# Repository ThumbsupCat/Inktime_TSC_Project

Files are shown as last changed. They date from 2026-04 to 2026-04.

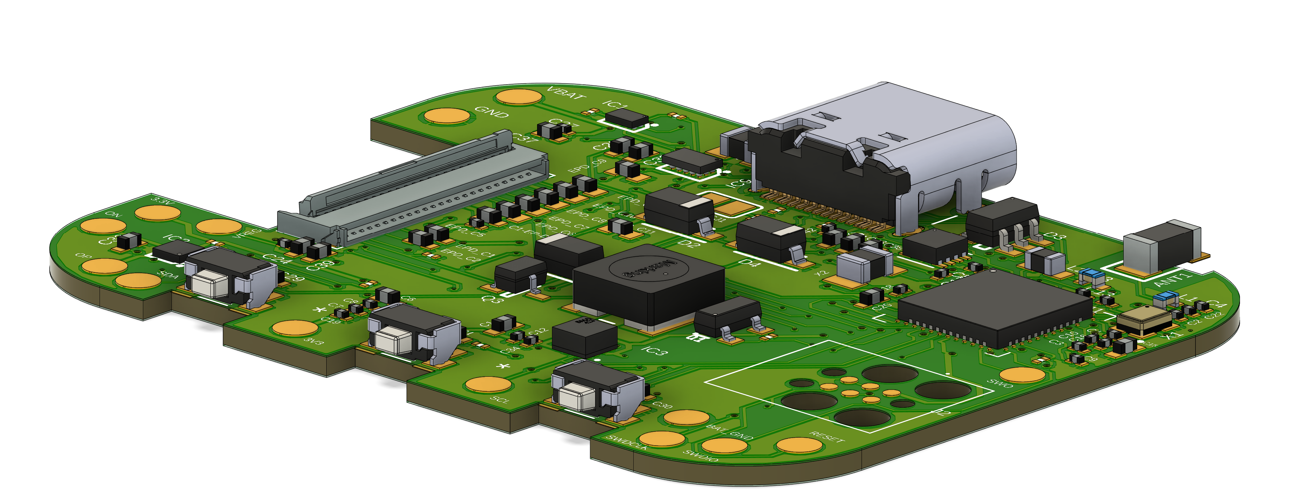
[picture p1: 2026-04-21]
Images/PCB_side_view.png

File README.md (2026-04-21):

# Inktime_TSC_Project

## Cuprins:

1. Hardware: - Schematicul si pcb-ul
2. Manufacturing: - Bill of Materials si Pick & Place
3. Mechanical: fisierele 3D
4. Images: Imaginile cu produsul final

## Descriere
InkTime este un ceas smart optimizat pentru autonomie maximă și lizibilitate 
în lumina soarelui. MVP-ul include:

- Display e-paper 1.54" (200×200) cu refresh parțial o dată pe minut
- Notificări BLE de pe telefon cu alertă haptic
- Numărare pași în timp real prin accelerometru cu pedometru integrat
- Încărcare USB-C și programare prin Tag-Connect TC2030 SWD

## Arhitectură
Sistemul este construit în jurul MCU-ului **nRF52840** care integrează 
procesor ARM Cortex-M4 și radio BLE 5.0.
Alimentarea este asigurată de un charger LiPo **BQ25180** conectat la 
USB-C și un regulator buck-boost **RT6160** care menține 3.3V stabil 
pe toată gama de descărcare a bateriei.

## Schema Bloc
Block Diagram

## Bill of Materials
| Ref | Component | Package | Funcție | LCSC | Datasheet |
|-----|---|---|---|---|---|
| U1 | nRF52840-QIAA | aQFN73 7×7mm | MCU + BLE 5.0 | [C190794](https://www.lcsc.com/product-detail/C190794.html) | [Datasheet](https://infocenter.nordicsemi.com/pdf/nRF52840_PS_v1.7.pdf) |
| IC1 | BQ25180YBGR | DSBGA-8 | Charger USB-C LiPo | [C3682423](https://www.lcsc.com/product-detail/C3682423.html)| [Datasheet](https://www.ti.com/lit/ds/symlink/bq25180.pdf) |
| IC9 | RT6160AWSC | WLCSP-15 | Regulator 3.3V buck-boost | [C7065276](https://www.lcsc.com/product-detail/C7065276.html) | [Datasheet](https://www.richtek.com/assets/product_file/RT6160A/DS6160A-00.pdf) |
| U3 | MAX17048G+T10 | DFN-8 2×2mm | Fuel gauge LiPo | [C2682616](https://www.lcsc.com/product-detail/C2682616.html) | [Datasheet](https://www.analog.com/media/en/technical-documentation/data-sheets/MAX17048-MAX17049.pdf) |
| IC3 | BMA421 | LGA-12 2×2mm | Accelerometru + pedometru | [C5242966](https://www.lcsc.com/product-detail/C5242966.html) | [Datasheet](https://www.bosch-sensortec.com/media/boschsensortec/downloads/datasheets/bst-bma421-ds000.pdf) |
| IC2 | DRV2605LDGSR | VSSOP-10 | Haptic driver ERM | [C527464](https://www.lcsc.com/product-detail/C527464.html) | [Datasheet](https://www.ti.com/lit/ds/symlink/drv2605l.pdf) |
| D3 | USBLC6-2SC6Y | SOT-363 | Protecție ESD USB | [C2687116](https://www.lcsc.com/product-detail/C2687116.html) | [Datasheet](https://www.st.com/resource/en/datasheet/usblc6-2.pdf) |
| Q1 | DMG2305UX-7 | SOT-323 | PFET EPD power gate | [C370432](https://www.lcsc.com/product-detail/C370432.html) | [Datasheet](https://www.diodes.com/assets/Datasheets/DMG2305UX.pdf) |
| Q3 | SI2301CDS | SOT-23 | PFET EPD gate control | [C10487](https://www.lcsc.com/product-detail/C10487.html) | [Datasheet](https://www.vishay.com/docs/70763/si2301cds.pdf) |
| J4 | KH-TYPE-C-16P | SMD | Conector USB-C | [C165948](https://www.lcsc.com/product-detail/C165948.html) | [Datasheet](https://datasheet.lcsc.com/lcsc/1912111437_Korean-Hroparts-Elec-TYPE-C-31-M-12_C165948.pdf) |
| J1 | 503480-2400 | SMD FPC | Conector display EPD 24 pini | [C393234](https://www.lcsc.com/product-detail/C393234.html) | [Datasheet](https://www.molex.com/pdm_docs/sd/5034802400_sd.pdf) |
| J2 | TC2030-IDC | PTH | Conector debug SWD Tag-Connect | - | [Datasheet](https://www.tag-connect.com/wp-content/uploads/bsk-pdf-manager/TC2030-IDC_1.pdf) |
| ANT1 | 2450AT18B100E | SMD | Antenă 2.4GHz BLE | - | [Datasheet](https://www.johansontechnology.com/datasheets/2450AT18B100E/2450AT18B100E.pdf) |
| L5 | WE-TPC 744042680 | 4828 | Inductor 68µH EPD boost | - | [Datasheet](https://www.we-online.com/catalog/datasheet/744042680.pdf) |
| L7 | FTC252012SR47MBCA | 0603 | Inductor 0.47µH RT6160 | - | - |
| X1 | NT2016SA-32MHz | 3225 | Crystal 32MHz MCU | - | - |
| X2 | Crystal 32.768kHz | 3215 | Crystal RTC | - | - |
| D2, D4, D5 | MBR0530T1G | SOD-123 | Diodă Schottky EPD driver | - | [Datasheet](https://www.onsemi.com/pdf/datasheet/mbr0530t1-d.pdf) |

## Pinii nRF52840

| Pin | Semnal | Componentă | Interfață |
|-----|---|---|---|
| P0.00/XL1 | XL1 | X2 32.768kHz crystal | Crystal RTC |
| P0.01/XL2 | XL2 | X2 32.768kHz crystal | Crystal RTC |
| P0.02 | SCK | EPD display | SPI |
| P0.03 | MOSI | EPD display | SPI |
| P0.05 | EPD_CS | EPD display | SPI CS |
| P0.06 | SDA | I2C bus (toți senzorii) | I2C |
| P0.07 | SCL | I2C bus (toți senzorii) | I2C |
| P0.08 | IMU_INT1 | BMA421 | GPIO interrupt |
| P0.12 | HAPTIC_EN | DRV2605L | GPIO enable |
| P0.13 | SW_UP | Buton UP | GPIO active-low |
| P0.14 | SW_DN | Buton DOWN | GPIO active-low |
| P0.15 | EPD_DC | EPD display | GPIO data/cmd |
| P0.16 | EPD_RST | EPD display | GPIO reset |
| P0.17 | EPD_BUSY | EPD display | GPIO busy |
| P0.18/RESET | RESET | TC2030 J2 | Hardware reset |
| P0.24 | SWDCLK | TC2030 J2 | SWD debug |
| P0.25 | SWDIO | TC2030 J2 | SWD debug |
| P1.00 | SW_ENT | Buton ENTER | GPIO active-low |
| P1.01 | EPD_3V3 gate | Q1 PFET | GPIO power gate EPD |
| P1.08 | IMU_INT2 | BMA421 | GPIO interrupt |
| VBUS | VBUS | J4 USB-C | USB 5V detect |
| D+ | DP | J4 USB-C | USB data+ |
| D- | DN | J4 USB-C | USB data- |
| ANT | RF | ANT1 2450AT18B100E | 2.4GHz BLE |

## Funcționalitate Hardware

### Power Path
USB-C (5V) → BQ25180 (charger + power path) → RT6160 (buck-boost 3.3V) → toți senzorii și MCU.
LiPo conectat la BQ25180 BAT. MAX17048 măsoară nivelul bateriei prin VBAT.
RT6160 menține 3.3V stabil pe toată gama de descărcare a bateriei (4.2V - 3.0V).

### MCU – nRF52840
Microcontroller ARM Cortex-M4 cu FPU, 64MHz, 1MB flash, 256KB RAM.
BLE 5.0 integrat cu antenă externă 2450AT18B100E plasată la exteriorul PCB-ului cu keepout sub ea.
Programare prin Tag-Connect TC2030 SWD (SWDIO, SWDCLK, RESET).

### Display E-Paper
Conector FPC 24 pini (J1) pentru panou e-paper 1.54" 200x200.
Comunicație SPI: SCK P0.02, MOSI P0.03, CS P0.05, DC P0.15, RST P0.16, BUSY P0.17.
Alimentare VEPD controlată prin PFET Q1 (gate P1.01) pentru power gating.
Circuit driver EPD: inductor L5 68µH, diode Schottky D2/D4/D5, condensatoare boost.

### IMU – BMA421
Accelerometru 3 axe cu pedometru integrat hardware.
Interfață I2C (adresă 0x18), INT1 pe P0.08 pentru wake-on-motion, INT2 pe P1.08.

### Haptic – DRV2605L
Driver motor ERM cu biblioteca de efecte haptic integrate.
Interfață I2C (adresă 0x5A), enable pe P0.12.
Motor ERM conectat direct la OUT+ și OUT-.

### Butoane
3 butoane tactile: UP (P0.13), DOWN (P0.14), ENTER (P1.00).
Configurație active-low cu pull-up intern activat în firmware.

### USB
Conector USB-C cu protecție ESD USBLC6 pe liniile D+/D-.
VBUS conectat la BQ25180 și la pinul de detecție al nRF52840.

### I2C Bus
Shared I2C pe SDA P0.06 / SCL P0.07 la 400kHz.
Dispozitive: BQ25180 (0x6A), RT6160 (0x75), MAX17048 (0x36), BMA421 (0x18), DRV2605L (0x5A).
Pull-up 10kΩ la 3.3V.

## PCB Design Notes

### Stackup
4 layere:
- Layer 1 (Top): semnal + componente SMD
- Layer 2: GND plane
- Layer 3: 3.3V power plane
- Layer 4 (Bottom): semnal

### Decizii de design
- GND rezolvat prin polygon pour pe toate layerele (Top, c2, Bottom)
- 3V3 rezolvat prin polygon pour pe layer-ul c63
- Antena 2450AT18B100E plasată la exteriorul boardului cu decupaj (keepout) 
  sub elementul radiant – fără cupru, fără trasee, fără plane sub antenă
- Condensatoare de decuplare plasate lângă pinii VCC ai fiecărui IC
- BMA421 plasat departe de motorul ERM pentru a evita false step counts
- Trasee de semnal: 0.15mm, trasee de power: 0.3mm

### Erori acceptate în DRC
- **Overlap Via-Smd - 6 erori approved**: via-uri în zona interioară a nRF52840 QFN73 
  din cauza densității extreme a pad-urilor. Nu pot fi rutate altfel in versiunea mea de rutare.
- **Copper Width - 2 erori approved**: trasee înguste (0.1mm) folosite pentru escape routing 
  din zona pinilor interiori ai MCU-ului unde spațiul nu permite 0.15mm.
- **Board Outline Clearance**: cauzate de modelul 3D al conectorului USB-C 
  care depășește ușor outline-ul – nu afectează fabricația.
- **Pad-Solid Polygon Shape, overlap**: footprintul pentru switchuri pe care l-am primit este facut prost.

### Probleme cunoscute
- Pinul RESET al nRF52840 rutat prin via escape din cauza
  poziției interioare în pachetul QFN73.
- Rutarea este foarte densă în zona nRF52840 din cauza 
  numărului mare de pini (73) și a spațiului limitat pe board.
  Acest lucru a necesitat trasee de 0.1mm și via-uri de escape
  pentru pinii din rândurile interioare ale chipului.

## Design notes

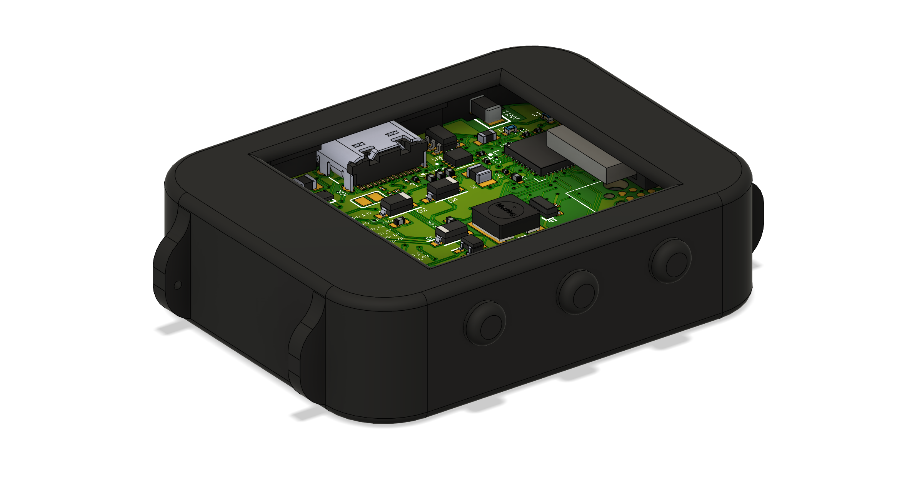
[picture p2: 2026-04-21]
Images/Case_w⁄o_display.png

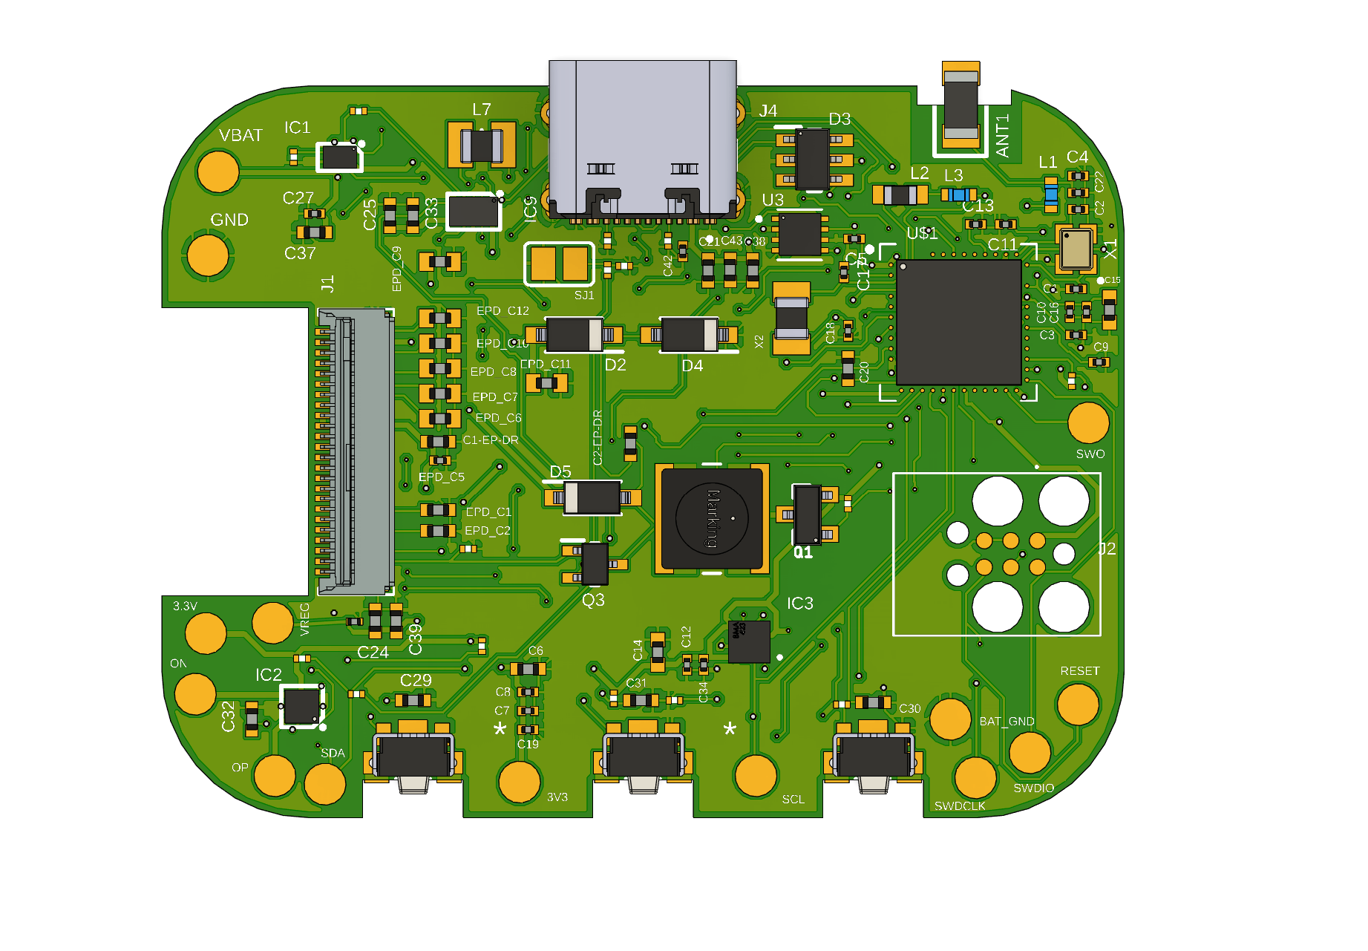
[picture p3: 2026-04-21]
Images/PCB_top_view.png

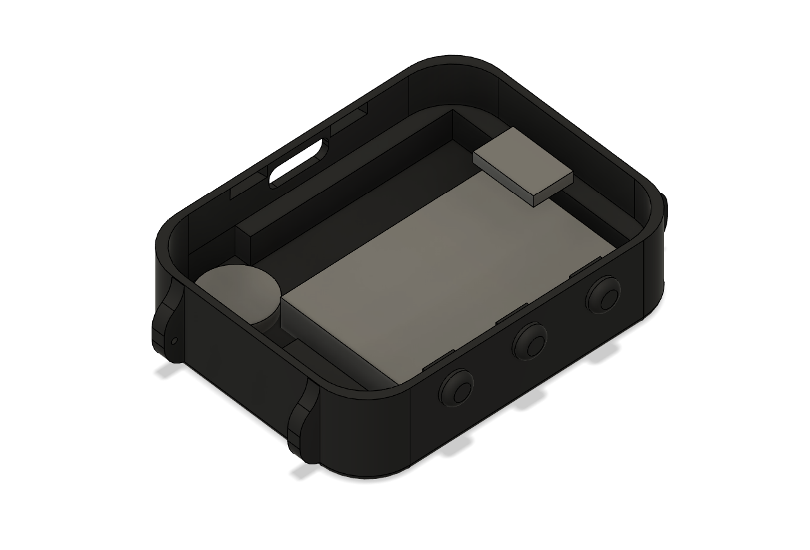
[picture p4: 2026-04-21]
Images/Empty_case.png

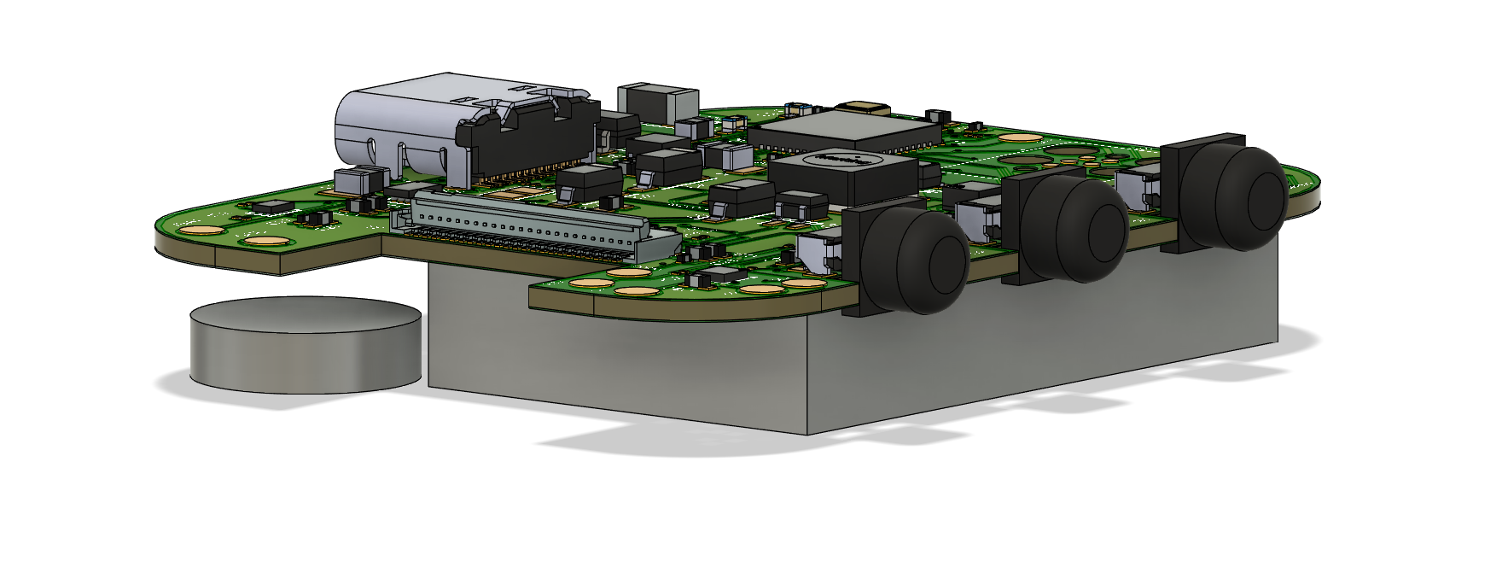
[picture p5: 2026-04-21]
Images/Inside_case.png

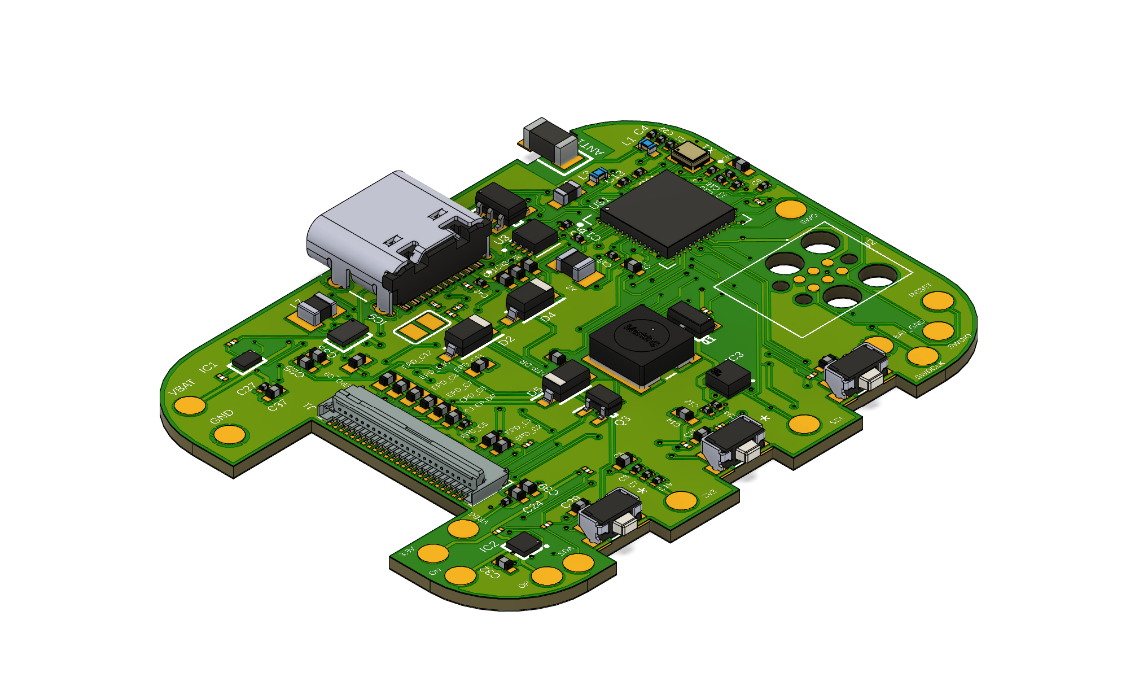
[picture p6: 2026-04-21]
Images/PCB_3⁄4_view.png

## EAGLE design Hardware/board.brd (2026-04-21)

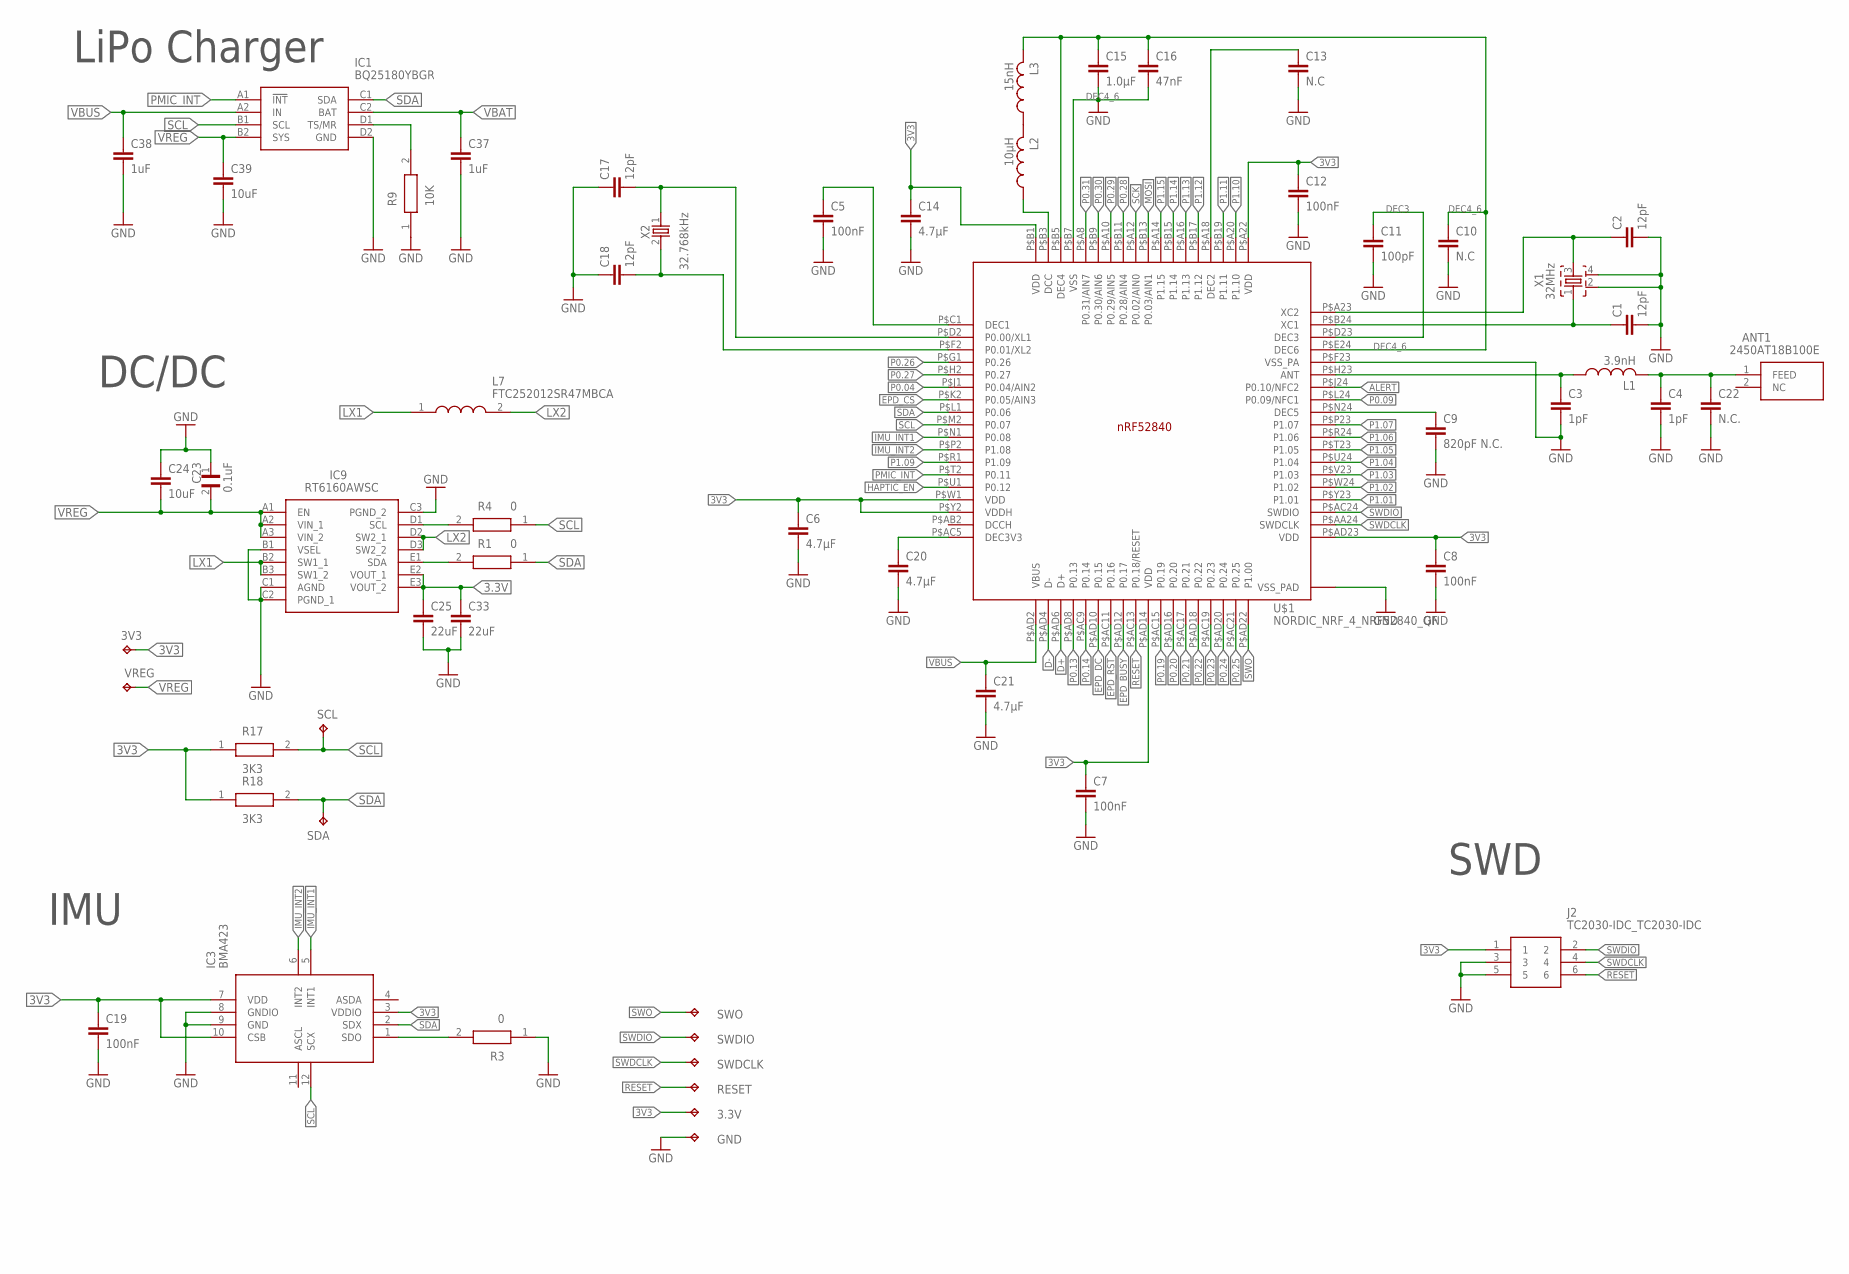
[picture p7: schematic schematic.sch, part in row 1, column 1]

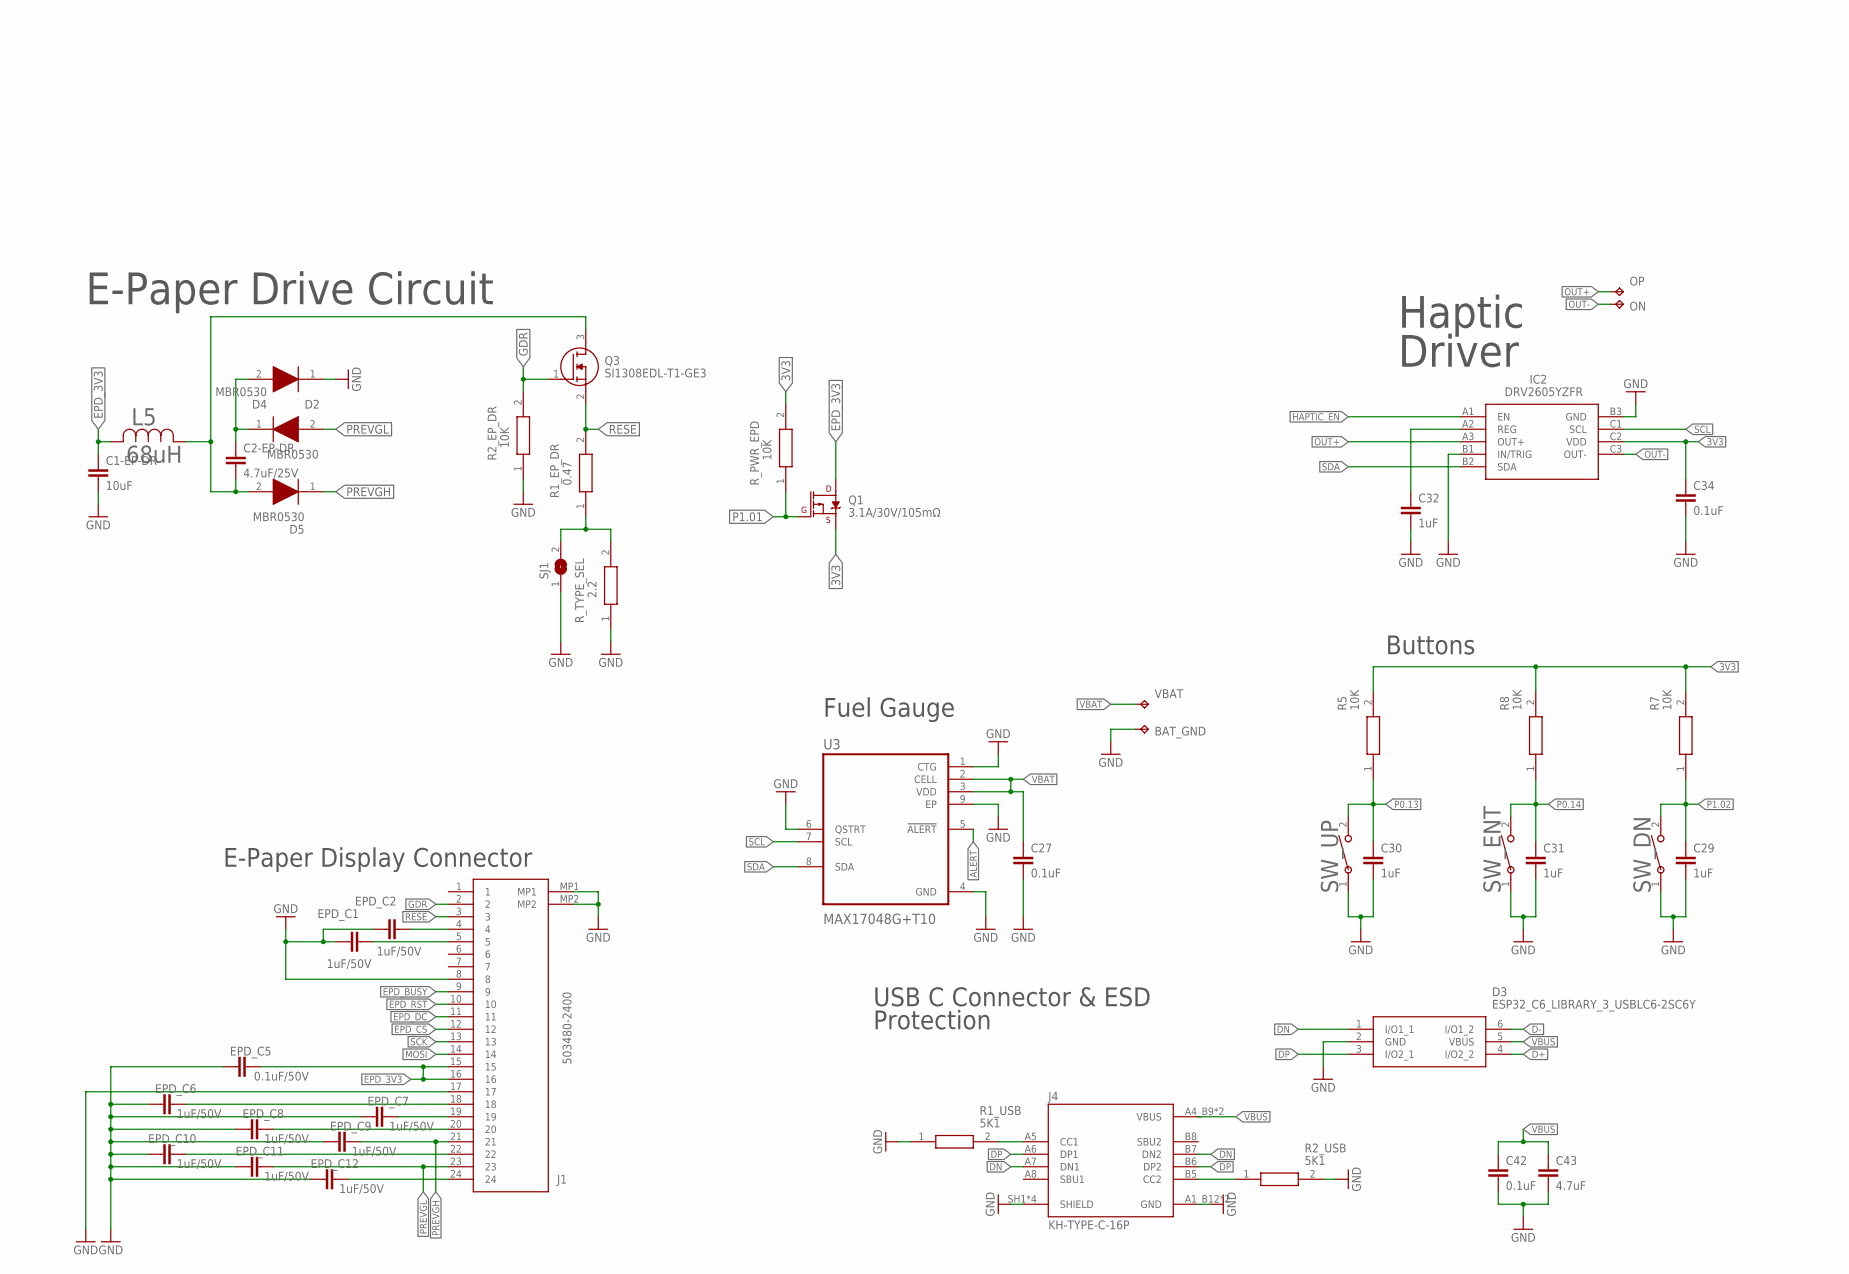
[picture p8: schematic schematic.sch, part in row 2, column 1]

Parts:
3.3V, 3V3: HECTOR_WATCH_1_TPTP20R; HECTOR_WATCH_1_TP20R
ANT1: 2450AT18B100E; 2450AT18B100E_ANTC3216X140N
BAT_GND: HECTOR_WATCH_1_TPTP20R; HECTOR_WATCH_1_TP20R
C1, C2, C17, C18: 12pF; NORDIC_NRF_3_RESC0201_N
C1-EP-DR, C24, C39: 10uF; NORDIC_NRF_3_RESC0402_N
C2-EP-DR: 4.7uF/25V; NORDIC_NRF_3_RESC0402_N
C3, C4: 1pF; NORDIC_NRF_3_RESC0201_N
C5, C7, C8, C12, C19: 100nF; NORDIC_NRF_3_RESC0201_N
C6, C20, C21: 4.7µF; NORDIC_NRF_3_RESC0402_N
C9: 820pF N.C.; NORDIC_NRF_3_RESC0201_N
C10, C13: N.C; NORDIC_NRF_3_RESC0201_N
C11: 100pF; NORDIC_NRF_3_RESC0201_N
C14: 4.7µF; NORDIC_NRF_3_RESC0402_M
C15: 1.0µF; NORDIC_NRF_3_RESC0402_M
C16: 47nF; NORDIC_NRF_3_RESC0201_N
C22: N.C.; NORDIC_NRF_3_RESC0201_N
C23: 0.1uF; GRM011R60J152KE01L_1_0201
C25, C33: 22uF; NORDIC_NRF_3_RESC0402_N
C27, C34, C42: 0.1uF; NORDIC_NRF_3_RESC0201_N
C29, C30, C31, C32, C37, C38: 1uF; NORDIC_NRF_3_RESC0402_N
C43: 4.7uF; NORDIC_NRF_3_RESC0402_N
D2, D4, D5: MBR0530; ESP32_C6_LIBRARY_5_SOD3716X135N
D3: ESP32_C6_LIBRARY_3_USBLC6-2SC6Y; ESP32_C6_LIBRARY_3_SOT95P280X145-6N
EPD_C1, EPD_C2: 1uF/50V; NORDIC_NRF_3_RESC0402_N
EPD_C5: 0.1uF/50V; NORDIC_NRF_3_RESC0201_N
EPD_C6, EPD_C7, EPD_C8, EPD_C9, EPD_C10, EPD_C11, EPD_C12: 1uF/50V; ESP32_C6_LIBRARY_1_ESP32_WROVER_EAGLE-LTSPICE_C0402
GND: HECTOR_WATCH_1_TPTP20R; HECTOR_WATCH_1_TP20R
IC1: BQ25180YBGR; BQ25180YBGR_BGA8C40P2X4_100X155X50
IC2: DRV2605YZFR; DRV2605YZFR_BGA9C50P3X3_144X144X62
IC3: BMA423; BMA423_BMA423
IC9: RT6160AWSC; RT6160AWSC_BGA15C40P3X5_140X230X60
J1: 503480-2400; 503480-2400_5034802400
J2: TC2030-IDC_TC2030-IDC; TC2030-IDC_TC2030IDC
J4: KH-TYPE-C-16P; KH-TYPE-C-16P_KINGHELM_KH-TYPE-C-16P
L1: 3.9nH; NORDIC_NRF_2_RESC0402_N
L2: 10µH; NORDIC_NRF_2_RESC0603_N
L3: 15nH; NORDIC_NRF_2_RESC0402_N
L5: 68uH; ESP32_C6_LIBRARY_2_IND_4828-WE-TPC_WRE
L7: FTC252012SR47MBCA; MLP2016SR47MT0S1_INDC2016X100N
ON: HECTOR_WATCH_1_TPTP20R; HECTOR_WATCH_1_TP20R
OP: HECTOR_WATCH_1_TPTP20R; HECTOR_WATCH_1_TP20R
Q1: 3.1A/30V/105mΩ; ESP32_C6_LIBRARY_4_ESP32_C6_LIBRARY_4_ESP32_C6_LIBRARY_4_ES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
Q3: SI1308EDL-T1-GE3; ESP32_C6_LIBRARY_6_SOT65P210X110-3N
R1, R3, R4: 0; ERA-1AEB3401C_0201
R1_EP_DR: 0.47; CPF0201D7K68C1_0201
R1_USB, R2_USB: 5K1; ERA-1AEB3401C_0201
R2_EP_DR, R5, R8, R9: 10K; CPF0201D7K68C1_0201
R7: 10K; ERA-1AEB3401C_0201
R17, R18: 3K3; CPF0201D7K68C1_0201
RESET: HECTOR_WATCH_1_TPTP20R; HECTOR_WATCH_1_TP20R
R_PWR_EPD: 10K; ERA-1AEB3401C_0201
R_TYPE_SEL: 2.2; ERA-1AEB3401C_0201
SCL: HECTOR_WATCH_1_TPTP20R; HECTOR_WATCH_1_TP20R
SDA: HECTOR_WATCH_1_TPTP20R; HECTOR_WATCH_1_TP20R
SJ1: ESP32_C6_LIBRARY_7_JUMPER_SJ
SWDCLK: HECTOR_WATCH_1_TPTP20R; HECTOR_WATCH_1_TP20R
SWDIO: HECTOR_WATCH_1_TPTP20R; HECTOR_WATCH_1_TP20R
SWO: HECTOR_WATCH_1_TPTP20R; HECTOR_WATCH_1_TP20R
SW_DN: 2025-10-22_07-23-44_LIBRARY_EVP-AKE31ASW_EVP-AKE3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; 2025-10-22_07-23-44_LIBRARY_SW_EVP-AKE31A_PAN
SW_ENT: 2025-10-22_07-23-44_LIBRARY_EVP-AKE31ASW_EVP-AKE3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; 2025-10-22_07-23-44_LIBRARY_SW_EVP-AKE31A_PAN
SW_UP: 2025-10-22_07-23-44_LIBRARY_EVP-AKE31ASW_EVP-AKE3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; 2025-10-22_07-23-44_LIBRARY_SW_EVP-AKE31A_PAN
U3: MAX17048G+T10; ESP32_C6_LIBRARY_SON50P200X200X80-9N
U$1: NORDIC_NRF_4_NRF52840_QF; NORDIC_NRF_4_AQFN50P700X700X85_HS-74N
VBAT: HECTOR_WATCH_1_TPTP20R; HECTOR_WATCH_1_TP20R
VREG: HECTOR_WATCH_1_TPTP20R; HECTOR_WATCH_1_TP20R
X1: 32MHz; NORDIC_NRF_BT-XTAL_2016_N
X2: 32.768kHz; NORDIC_NRF_1_XTAL_3215_N

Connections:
3.3V: C25.1, C33.1, IC9.E2 (VOUT_1), IC9.E3 (VOUT_2)
3V3: 3.3V.TP, 3V3.TP, C6.1, C7.1, C8.1, C12.1, C14.1, C19.1, C34.1, IC2.C2 (VDD), IC3.3 (VDDIO), IC3.7 (VDD), IC3.10 (CSB), J2.1, Q1.2 (S), R5.2, R7.2, R8.2, R17.1, R18.1, R_PWR_EPD.2, U$1.P$A22 (VDD), U$1.P$AD14 (VDD), U$1.P$AD23 (VDD), U$1.P$B1 (VDD), U$1.P$W1 (VDD), U$1.P$Y2 (VDDH)
ALERT: U3.5 (!ALERT), U$1.P$J24 (P0.10/NFC2)
D+: D3.4 (I/O2_2), U$1.P$AD6 (D+)
D-: D3.6 (I/O1_2), U$1.P$AD4 (D-)
DEC3: C11.1, U$1.P$D23 (DEC3)
DEC4_6: C10.1, C15.1, C16.1, L3.2, U$1.P$B5 (DEC4), U$1.P$E24 (DEC6)
DN: D3.1 (I/O1_1), J4.A7 (DN1), J4.B7 (DN2)
DP: D3.3 (I/O2_1), J4.A6 (DP1), J4.B6 (DP2)
EPD_3V3: C1-EP-DR.1, EPD_C5.2, J1.15, J1.16, L5.2, Q1.3 (D)
EPD_BUSY: J1.9, U$1.P$AD12 (P0.17)
EPD_CS: J1.12, U$1.P$K2 (P0.05/AIN3)
EPD_DC: J1.11, U$1.P$AD10 (P0.15)
EPD_RST: J1.10, U$1.P$AC11 (P0.16)
GDR: J1.2, Q3.1 (G), R2_EP_DR.2
GND: BAT_GND.TP, C1.2, C1-EP-DR.2, C2.2, C3.2, C4.2, C5.2, C6.2, C7.2, C8.2, C9.2, C10.2, C11.2, C12.2, C13.2, C14.2, C15.2, C16.2, C17.1, C18.1, C19.2, C20.2, C21.2, C22.2, C23.1, C24.1, C25.2, C27.2, C29.2, C30.2, C31.2, C32.2, C33.2, C34.2, C37.2, C38.2, C39.2, C42.2, C43.2, D3.2 (GND), D4.1 (K), EPD_C1.1, EPD_C2.1, EPD_C5.1, EPD_C6.1, EPD_C7.1, EPD_C8.1, EPD_C9.1, EPD_C10.1, EPD_C11.1, EPD_C12.1, GND.TP, IC1.D2 (GND), IC2.B1 (IN/TRIG), IC2.B3 (GND), IC3.8 (GNDIO), IC3.9 (GND), IC9.B1 (VSEL), IC9.C1 (AGND), IC9.C2 (PGND_1), IC9.C3 (PGND_2), J1.8, J1.17, J1.MP1, J1.MP2, J2.3, J2.5, J4.A1_B12 (GND), J4.A12_B1 (GND), J4.SH1 (SHIELD), J4.SH2 (SHIELD), J4.SH3 (SHIELD), J4.SH4 (SHIELD), R1_USB.1, R2_EP_DR.1, R2_USB.2, R3.1, R9.1, R_TYPE_SEL.1, SJ1.1, SW_DN.1, SW_ENT.1, SW_UP.1, U3.1 (CTG), U3.4 (GND), U3.6 (QSTRT), U3.9 (EP), U$1.P$74 (VSS_PAD), U$1.P$75 (VSS_PAD), U$1.P$76 (VSS_PAD), U$1.P$77 (VSS_PAD), U$1.P$78 (VSS_PAD), U$1.P$79 (VSS_PAD), U$1.P$80 (VSS_PAD), U$1.P$81 (VSS_PAD), U$1.P$82 (VSS_PAD), U$1.P$83 (VSS_PAD), U$1.P$84 (VSS_PAD), U$1.P$85 (VSS_PAD), U$1.P$86 (VSS_PAD), U$1.P$87 (VSS_PAD), U$1.P$88 (VSS_PAD), U$1.P$89 (VSS_PAD), U$1.P$90 (VSS_PAD), U$1.P$B7 (VSS), U$1.P$F23 (VSS_PA), X1.2, X1.4
HAPTIC_EN: IC2.A1 (EN), U$1.P$U1 (P0.12)
IMU_INT1: IC3.5 (INT1), U$1.P$N1 (P0.08)
IMU_INT2: IC3.6 (INT2), U$1.P$P2 (P1.08)
LX1: IC9.B2 (SW1_1), IC9.B3 (SW1_2), L7.1
LX2: IC9.D2 (SW2_1), IC9.D3 (SW2_2), L7.2
MOSI: J1.14, U$1.P$B13 (P0.03/AIN1)
unnamed: C5.1, U$1.P$C1 (DEC1)
unnamed: C17.2, U$1.P$D2 (P0.00/XL1), X2.1
unnamed: IC1.D1 (TS/MR), R9.2
unnamed: C18.2, U$1.P$F2 (P0.01/XL2), X2.2
unnamed: L2.1, U$1.P$B3 (DCC)
unnamed: IC9.D1 (SCL), R4.2
unnamed: C20.1, U$1.P$AC5 (DEC3V3)
unnamed: IC9.E1 (SDA), R1.2
unnamed: IC3.1 (SDO), R3.2
unnamed: L2.2, L3.1
unnamed: C13.1, U$1.P$A18 (DEC2)
unnamed: C2.1, U$1.P$A23 (XC2), X1.3
unnamed: C1.1, U$1.P$B24 (XC1), X1.1
unnamed: ANT1.1 (FEED), C4.1, C22.1, L1.2
unnamed: C3.1, L1.1, U$1.P$H23 (ANT)
unnamed: C2-EP-DR.2, D5.2 (A), L5.1, Q3.3 (D)
unnamed: C2-EP-DR.1, D2.1 (K), D4.2 (A)
unnamed: C9.1, U$1.P$N24 (DEC5)
unnamed: R1_EP_DR.1, R_TYPE_SEL.2, SJ1.2
unnamed: EPD_C12.2, J1.24
unnamed: EPD_C6.2, J1.18
unnamed: J4.A5 (CC1), R1_USB.2
unnamed: C32.1, IC2.A2 (REG)
unnamed: EPD_C10.2, J1.22
unnamed: J4.B5 (CC2), R2_USB.1
unnamed: EPD_C8.2, J1.20
unnamed: EPD_C7.2, J1.19
unnamed: EPD_C2.2, J1.4
unnamed: EPD_C1.2, J1.5
OUT+: IC2.A3 (OUT+), OP.TP
OUT-: IC2.C3 (OUT-), ON.TP
P0.04: U$1.P$J1 (P0.04/AIN2)
P0.09: U$1.P$L24 (P0.09/NFC1)
P0.13: C30.1, R5.1, SW_UP.2, U$1.P$AD8 (P0.13)
P0.14: C31.1, R8.1, SW_ENT.2, U$1.P$AC9 (P0.14)
P0.19: U$1.P$AC15 (P0.19)
P0.20: U$1.P$AD16 (P0.20)
P0.21: U$1.P$AC17 (P0.21)
P0.22: U$1.P$AD18 (P0.22)
P0.23: U$1.P$AC19 (P0.23)
P0.24: U$1.P$AD20 (P0.24)
P0.25: U$1.P$AC21 (P0.25)
P0.26: U$1.P$G1 (P0.26)
P0.27: U$1.P$H2 (P0.27)
P0.28: U$1.P$B11 (P0.28/AIN4)
P0.29: U$1.P$A10 (P0.29/AIN5)
P0.30: U$1.P$B9 (P0.30/AIN6)
P0.31: U$1.P$A8 (P0.31/AIN7)
P1.01: Q1.1 (G), R_PWR_EPD.1, U$1.P$Y23 (P1.01)
P1.02: C29.1, R7.1, SW_DN.2, U$1.P$W24 (P1.02)
P1.03: U$1.P$V23 (P1.03)
P1.04: U$1.P$U24 (P1.04)
P1.05: U$1.P$T23 (P1.05)
P1.06: U$1.P$R24 (P1.06)
P1.07: U$1.P$P23 (P1.07)
P1.09: U$1.P$R1 (P1.09)
P1.10: U$1.P$A20 (P1.10)
P1.11: U$1.P$B19 (P1.11)
P1.12: U$1.P$B17 (P1.12)
P1.13: U$1.P$A16 (P1.13)
P1.14: U$1.P$B15 (P1.14)
P1.15: U$1.P$A14 (P1.15)
PMIC_INT: IC1.A1 (!INT), U$1.P$T2 (P0.11)
PREVGH: D5.1 (K), EPD_C9.2, J1.21
PREVGL: D2.2 (A), EPD_C11.2, J1.23
RESE: J1.3, Q3.2 (S), R1_EP_DR.2
RESET: J2.6, RESET.TP, U$1.P$AC13 (P0.18/RESET)
SCK: J1.13, U$1.P$A12 (P0.02/AIN0)
SCL: IC1.B1 (SCL), IC2.C1 (SCL), IC3.12 (SCX), R4.1, R17.2, SCL.TP, U3.7 (SCL), U$1.P$M2 (P0.07)
SDA: IC1.C1 (SDA), IC2.B2 (SDA), IC3.2 (SDX), R1.1, R18.2, SDA.TP, U3.8 (SDA), U$1.P$L1 (P0.06)
SWDCLK: J2.4, SWDCLK.TP, U$1.P$AA24 (SWDCLK)
SWDIO: J2.2, SWDIO.TP, U$1.P$AC24 (SWDIO)
SWO: SWO.TP, U$1.P$AD22 (P1.00)
VBAT: C27.1, C37.1, IC1.C2 (BAT), U3.2 (CELL), U3.3 (VDD), VBAT.TP
VBUS: C21.1, C38.1, C42.1, C43.1, D3.5 (VBUS), IC1.A2 (IN), J4.A4_B9 (VBUS), J4.A9_B4 (VBUS), U$1.P$AD2 (VBUS)
VREG: C23.2, C24.2, C39.1, IC1.B2 (SYS), IC9.A1 (EN), IC9.A2 (VIN_1), IC9.A3 (VIN_2), VREG.TP

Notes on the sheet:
LiPo Charger
DC/DC
IMU
SWD
E-Paper Drive Circuit
Haptic Driver
E-Paper Display Connector
Fuel Gauge
Buttons
USB C Connector & ESD Protection

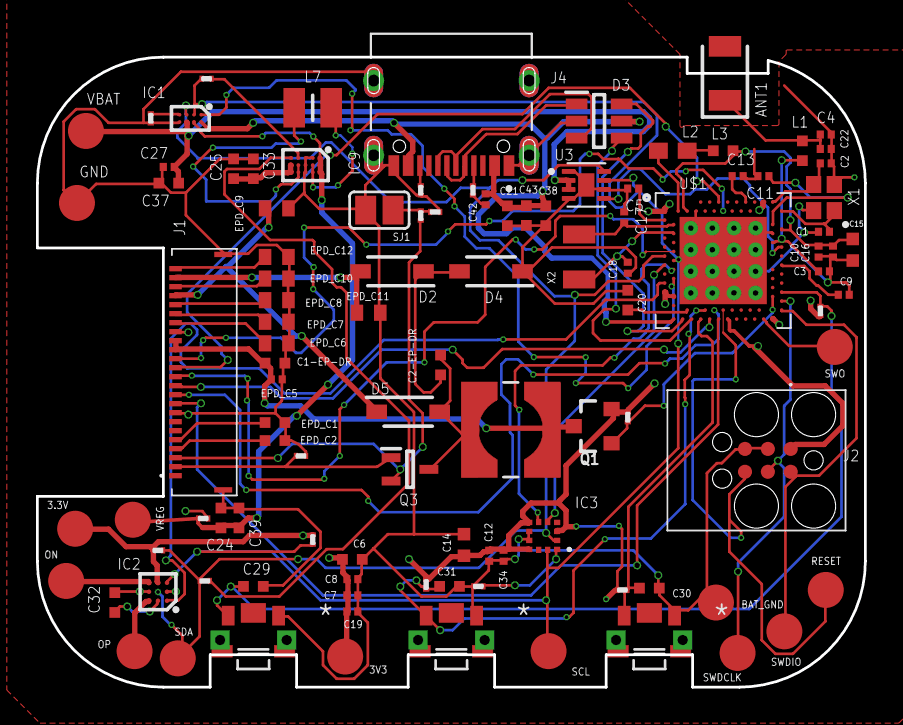
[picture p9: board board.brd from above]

Board: 4 copper layers, 46.0 x 35.0 mm, 105 parts (0 on the bottom side), 71 nets.

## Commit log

2026-04-10 Add files via upload
    Added schematic and board files
    [board.brd, schematic.sch]
2026-04-10 moved board.brd to Hardware/board.brd
    [board.brd]
2026-04-10 moved schematic.sch to Hardware/schematic.sch
    [schematic.sch]
2026-04-10 Add files via upload
    Todo
    [Bill_of_materials.csv]
2026-04-21 Schematic and 2D PCB updated to final version
    [board.brd, schematic.sch]
2026-04-21 Manufacturing and mechanical files uploaded, dummies deleted
    [Bill_of_materials.csv]

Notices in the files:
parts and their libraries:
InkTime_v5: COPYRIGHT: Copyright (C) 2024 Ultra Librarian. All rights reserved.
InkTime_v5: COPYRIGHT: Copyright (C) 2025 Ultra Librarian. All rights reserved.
